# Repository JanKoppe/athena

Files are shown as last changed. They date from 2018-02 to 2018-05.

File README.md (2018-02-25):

# Athena

_2.1 audio crossover and headphone amplifier_

This is a work-in-progress on a simple 2.1 audio crossover using active 2nd-order RC filters, as well as a headphone amplifier based on the popular CMoy design. The PCBs have not yet been ordered and confirmed.

## Crossover frequency

The crossover frequency is set by the resistors R11-R16 and the capacitors C5-C10. Keep the values for all components the same.

equation

Using a fixed, commonly available 100nF capacitor the following (and more) corner frequencies can be set:

Resistance | Frequency
-----------|----------
22 kOhms   |  72,34 Hz
20 kOhms   |  79,57 Hz
18 kOhms   |  88,42 Hz
16 kOhms   |  99,47 Hz
15 kOhms   | 106,10 Hz
13 kOhms   | 122,48 Hz
12 kOhms   | 132,64 Hz

## Power supply

The unit should be powered by at least 12 volts DC, but no more than 30 volts DC. More voltage will give you higher headroom for greater amplification (headphone) and high-level signal handling, though you should be able to use a regular 12 volts DC power supply for consumer line levels.

__Attention:__ The power supply must _never_ be connected to signal ground because this schematic referencing ground to VCC/2, i.e. the power supply ground is actually the negative voltage rail. Using a wall wart power supply you should not run into any issues. This avoids adding large capacitors in series on the outputs.

## Enclosure

Use Fischer Elektronik KOH-1100 and KOH-2100 case components with lasercut panels from 2mm plexiglas for the enclosure. CAD files for panel cutouts are included.

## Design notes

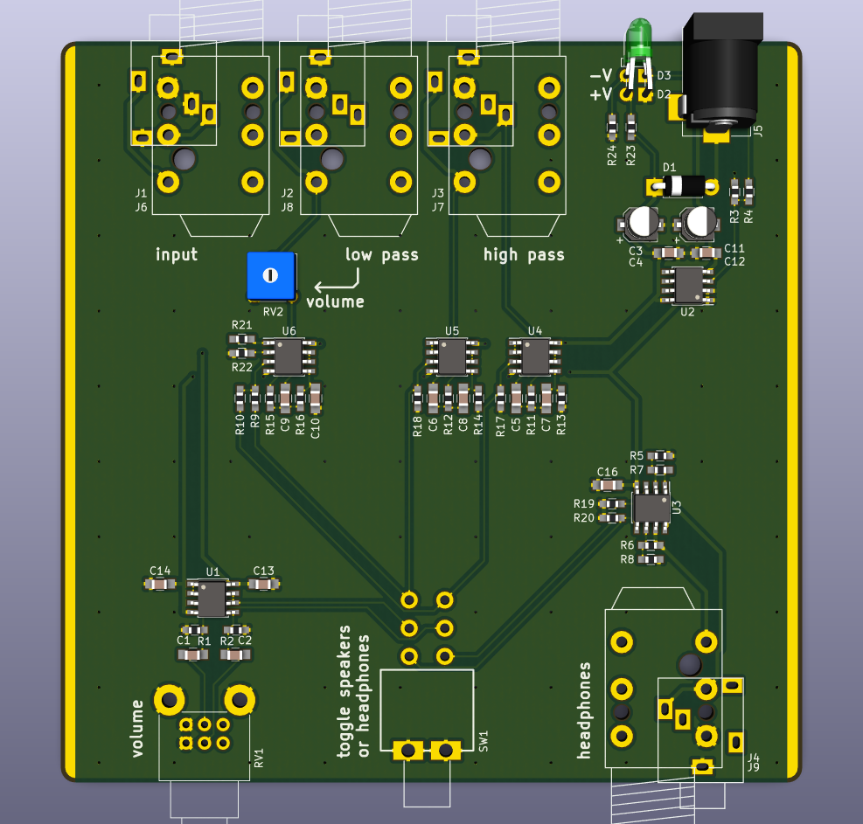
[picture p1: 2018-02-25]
3d_top.png

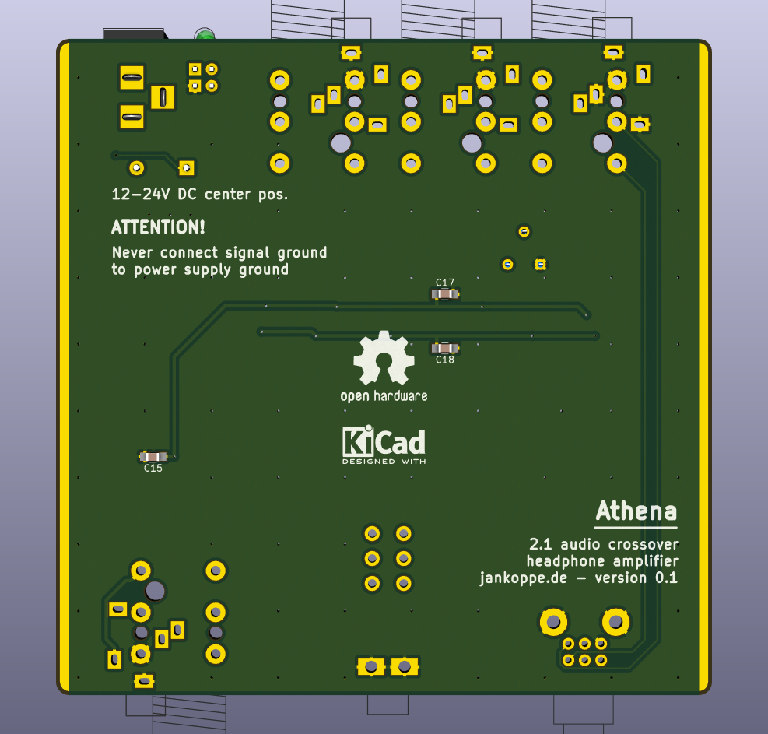
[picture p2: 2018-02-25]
3d_bottom.png

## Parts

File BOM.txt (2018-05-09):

4x NE5532 SOIC-8 (U1, U4-6) (input buffer and active filters for speaker outputs)
1x OPA2134 SOIC-8 (U3) (opamp for cmoy, needs beefy output)
1x TL072 SOIC-8 (U2) (voltage rail splitter buffer)
2x 10u/16v smd electrolytic capacitor (C3, C11)
16x 100n 0805 ceramic capacitor (all other C)
6x 10k 0603 resistor (R3, R4, R9, R10, R21, R22)
6x 100k 0603 resistor (R1, R2, R17-20)
6x 22k 0603 resistor (R11-16)
2x 2k7 0603 resistor (R5, R6)
2x 8k2 0603 resistor (R7, R8)
2x 330r resistor (R23, R24) (current-limiting resistors for voltage leds)
2x 3mm LED of your choice (D2, D3) (voltage indicator leds)
1x 1n4001 diode (D1)
1x 10k single turn trimmer, flat, legs (RV2) - sub volume
1x alps RK09L12B 10k log stereo potentiometer (RV1) - main volume
1x "MS 500FVT"@reichelt.de switch, DPDT (SW1)
1x standard DC 2.1mm pcb-mount jack

Input/Output Jacks can be selected to your liking between 3.5mm and 6.3mm jacks, you will need a total of 4 jacks:
Neutrik NRJ6HF for 6.3mm and corresponding nut
Lumberg 1503-09 for 3.5mm

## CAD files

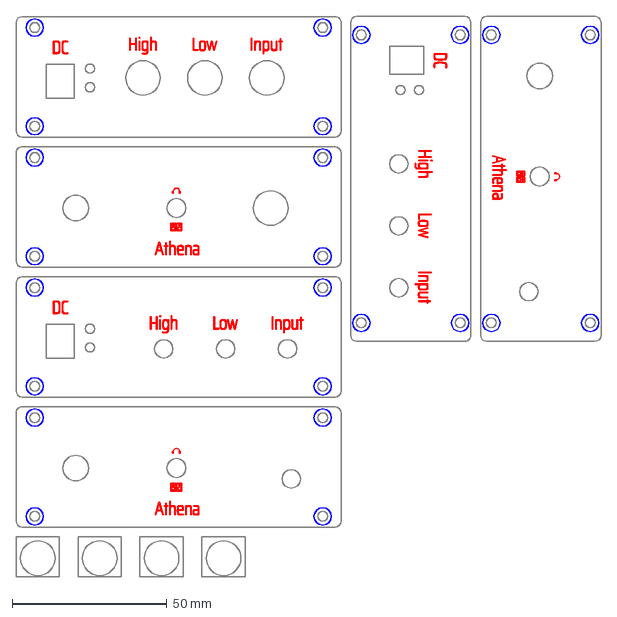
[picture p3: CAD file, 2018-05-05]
panels/panels.dxf
188.9 x 181.0 mm

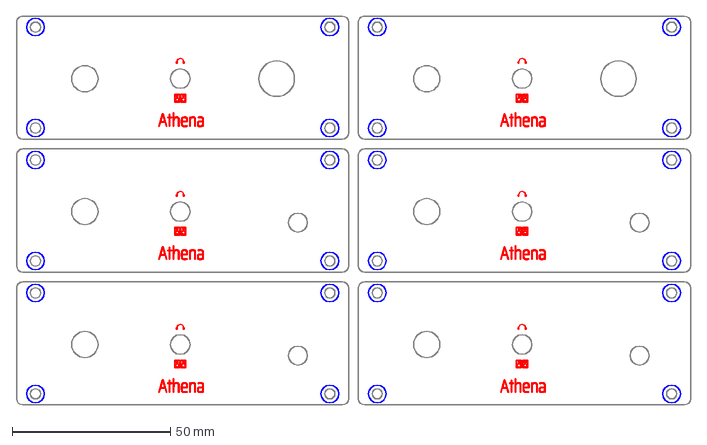
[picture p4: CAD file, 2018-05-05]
panels/panels_fixed_front.dxf
213.0 x 122.9 mm

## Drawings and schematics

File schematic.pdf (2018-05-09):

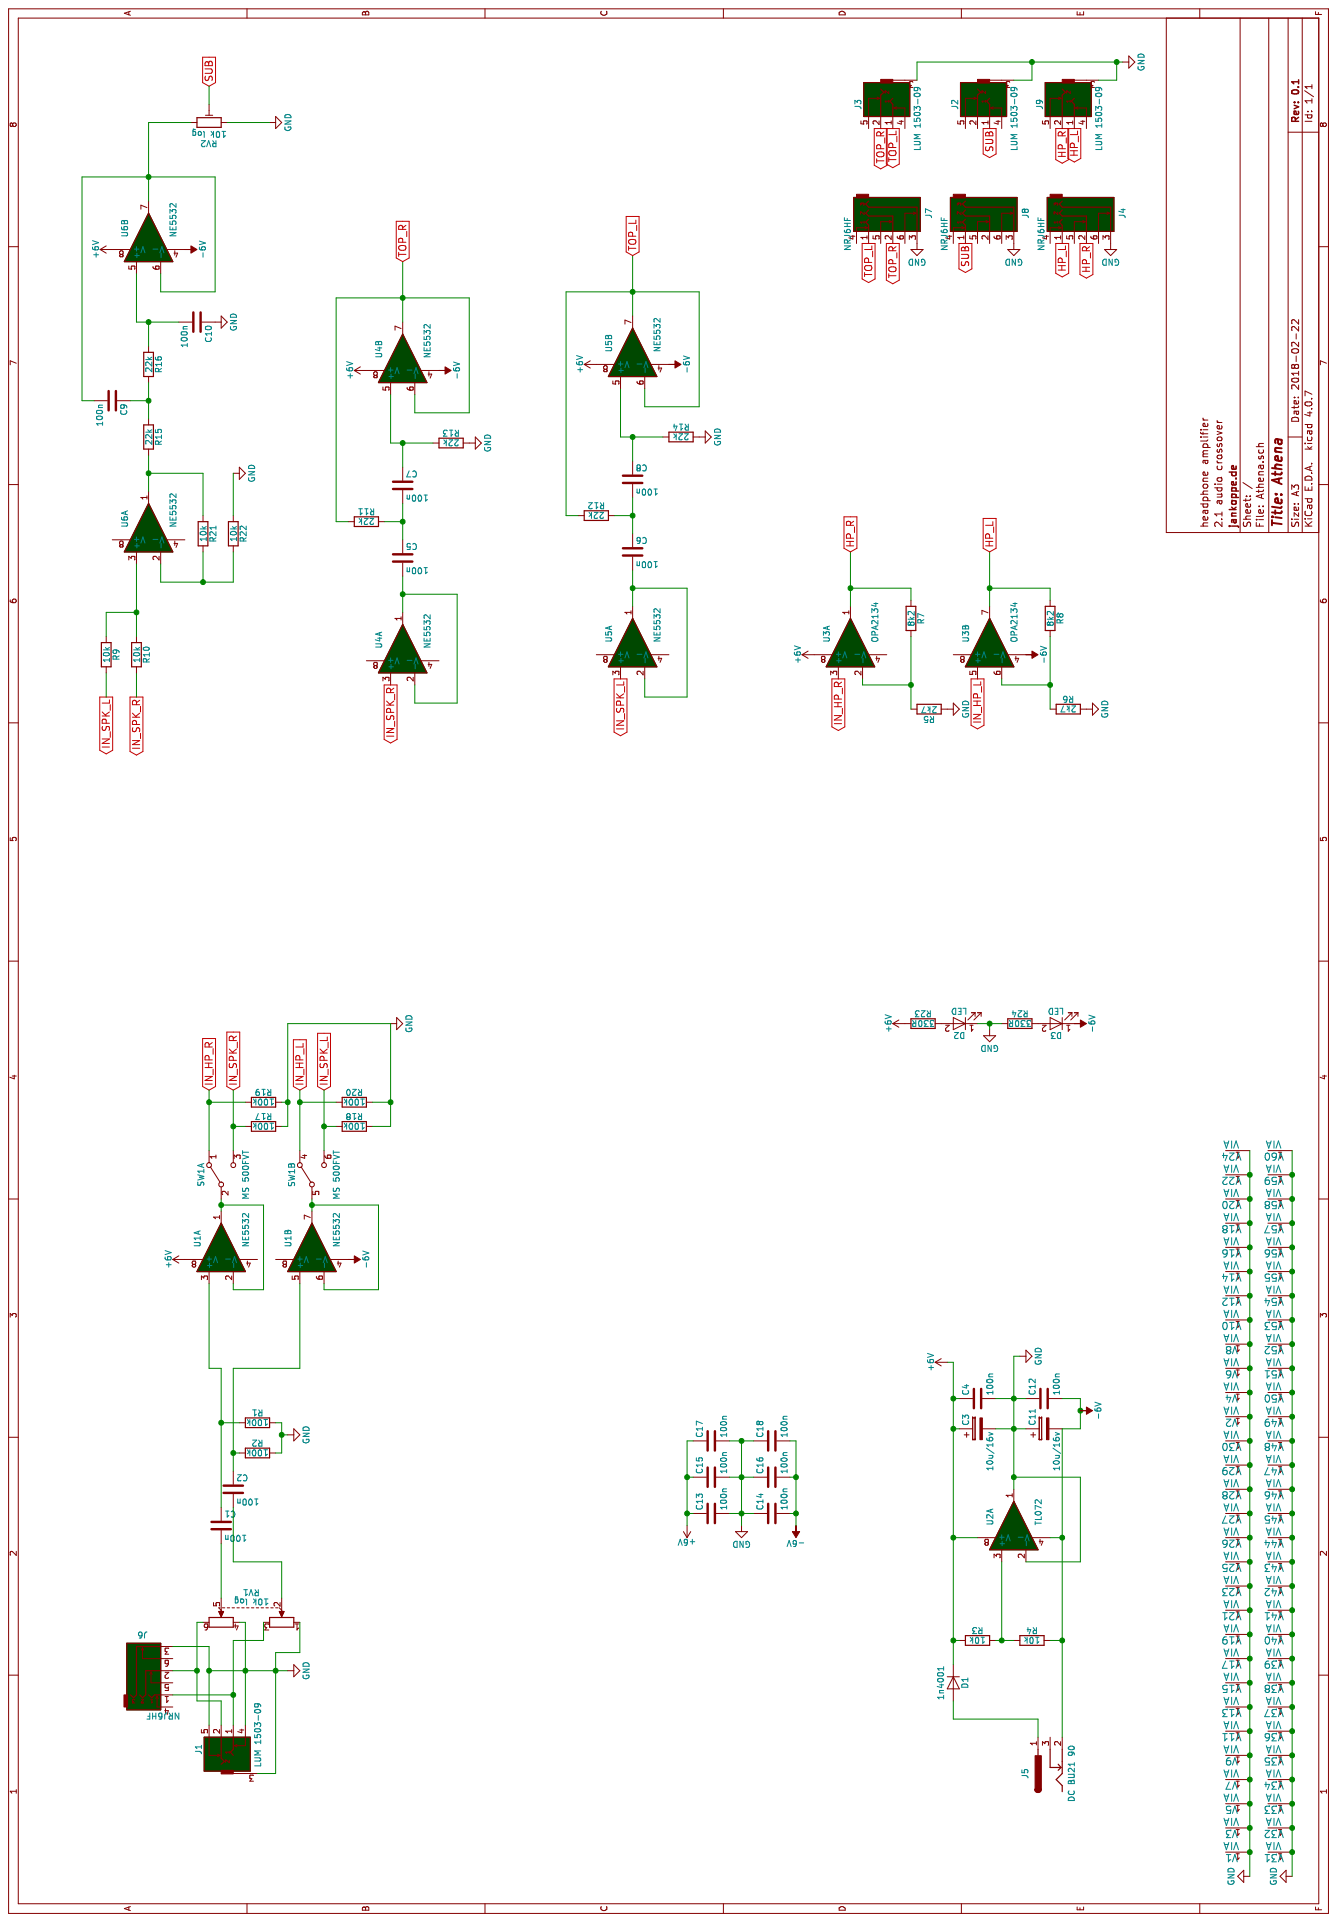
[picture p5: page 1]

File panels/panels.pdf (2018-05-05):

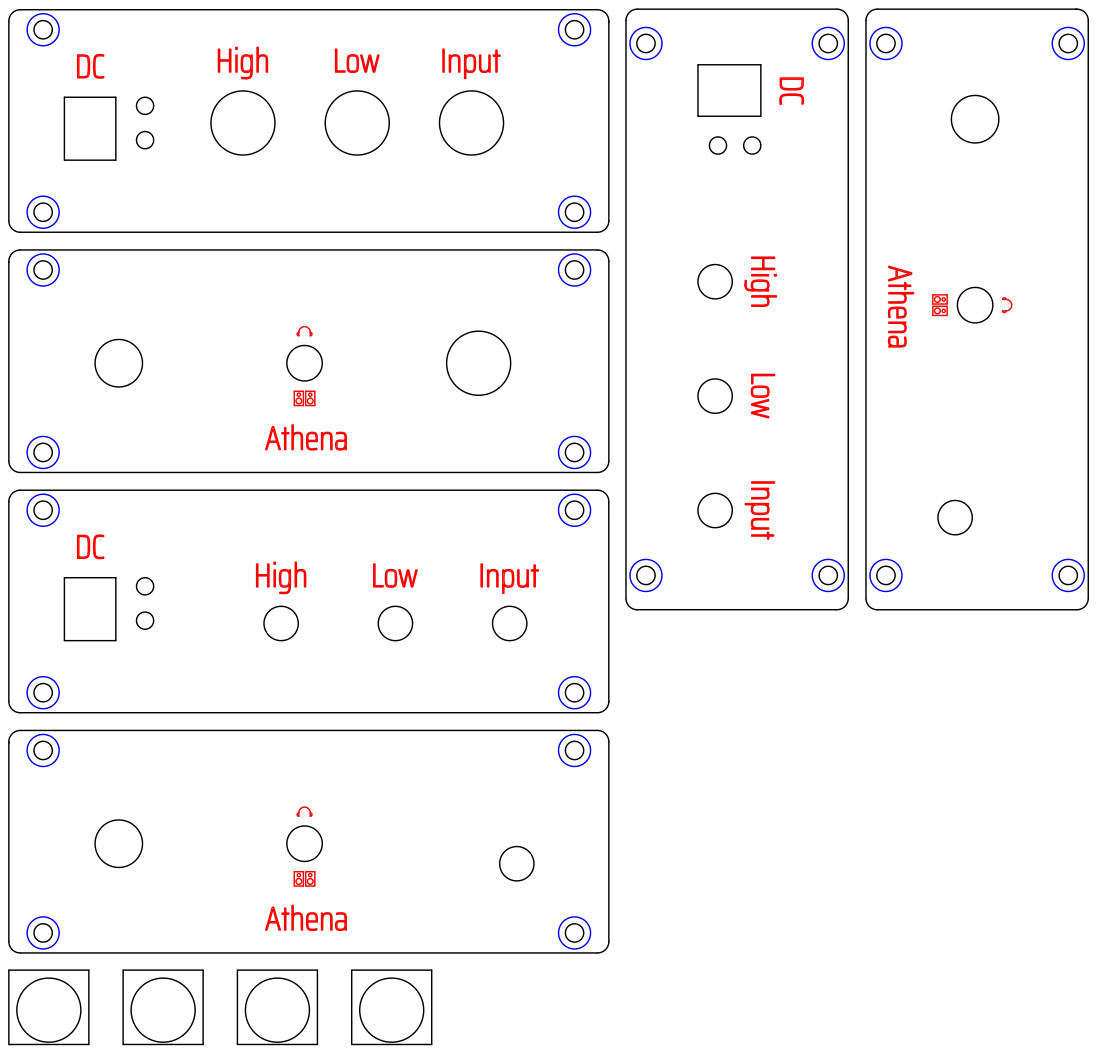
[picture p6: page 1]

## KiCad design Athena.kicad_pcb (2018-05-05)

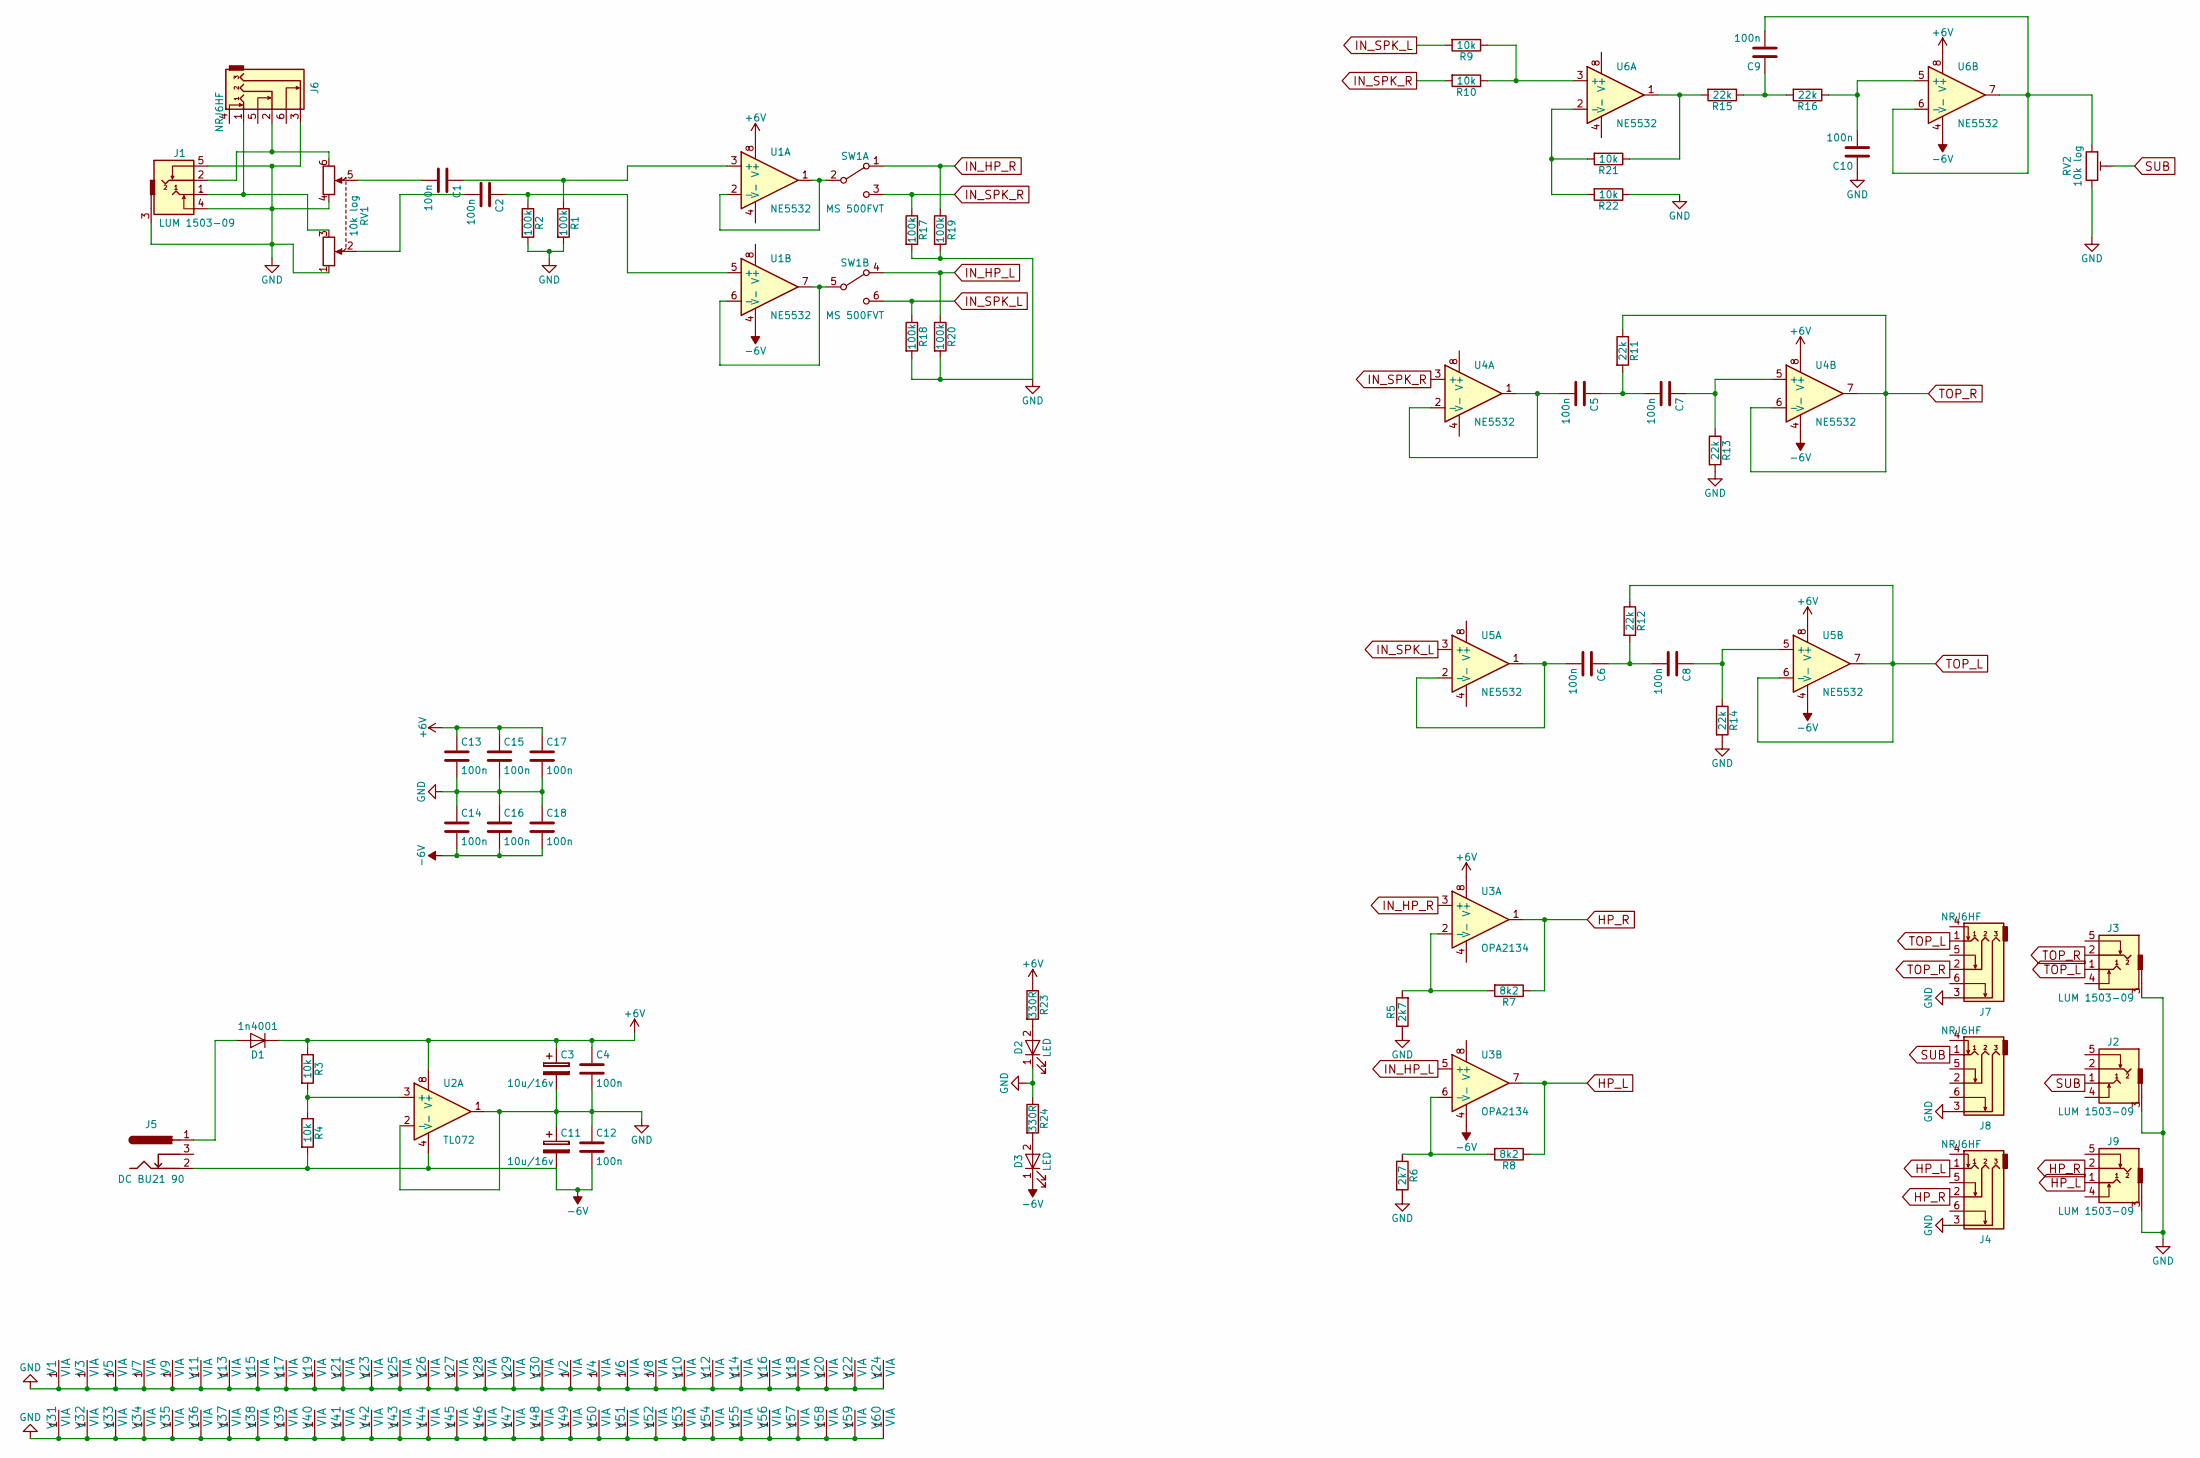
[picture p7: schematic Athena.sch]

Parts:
C1, C2, C4, C5, C6, C7, C8, C9, C10, C12, C13, C14, C15, C16, C17, C18: 100n; C_0805_HandSoldering
C3, C11: 10u/16v; CP_Elec_4x5.3
D1: 1n4001; D_DO-41_SOD81_P7.62mm_Horizontal
D2: LED; LED_D3.0mm_Horizontal_O3.81mm_Z6.0mm
D3: LED; LED_D3.0mm_Horizontal_O1.27mm_Z2.0mm
J1, J2, J3, J9: LUM 1503-09; LUM1503-09
J4, J6, J7, J8: NRJ6HF
J5: DC BU21 90; BARREL_JACK
R1, R2, R17, R18, R19, R20: 100k; R_0603_HandSoldering
R3, R4, R9, R10, R21, R22: 10k; R_0603_HandSoldering
R5, R6: 2k7; R_0603_HandSoldering
R7, R8: 8k2; R_0603_HandSoldering
R11, R12, R13, R14, R15, R16: 22k; R_0603_HandSoldering
R23, R24: 330R; R_0603_HandSoldering
RV1: 10k log; Potentiometer_Alps_RK09L_Double_Vertical
RV2: 10k log; Potentiometer_Trimmer_ACP_CA6v_Horizontal
SW1: MS 500FVT; MS500FVT
U1, U4, U5, U6: NE5532; SOIC-8_3.9x4.9mm_Pitch1.27mm
U2: TL072; SOIC-8_3.9x4.9mm_Pitch1.27mm
U3: OPA2134; SOIC-8_3.9x4.9mm_Pitch1.27mm
V1, V2, V3, V4, V5, V6, V7, V8, V9, V10, V11, V12, V13, V14, V15, V16, V17, V18, V19, V20, V21, V22, V23, V24, V25, V26, V27, V28, V29, V30, V31, V32, V33, V34, V35, V36, V37, V38, V39, V40, V41, V42, V43, V44, V45, V46, V47, V48, V49, V50, V51, V52, V53, V54, V55, V56, V57, V58, V59, V60: VIA; VIA-0.6

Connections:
+6V: C3.1, C4.1, C13.1, C15.1, C17.1, D1.1 (K), R3.1, R23.1, U1.8 (V+), U2.8 (V+), U3.8 (V+), U4.8 (V+), U5.8 (V+), U6.8 (V+)
-6V: C11.2, C12.2, C14.2, C16.2, C18.2, D3.1 (K), J5.2, R4.2, U1.4 (V-), U2.4 (V-), U3.4 (V-), U4.4 (V-), U5.4 (V-), U6.4 (V-)
GND: C3.2, C4.2, C10.1, C11.1, C12.1, C13.2, C14.1, C15.2, C16.1, C17.2, C18.1, D2.1 (K), J1.3, J1.4, J1.5, J2.3, J3.3, J4.3, J6.3, J7.3, J8.3, J9.3, R1.2, R2.2, R5.1, R6.2, R13.2, R14.2, R17.2, R18.2, R19.2, R20.2, R22.1, R24.1, RV1.0, RV1.1, RV1.4, RV2.3, U2.1, U2.2 (-), V1.1, V2.1, V3.1, V4.1, V5.1, V6.1, V7.1, V8.1, V9.1, V10.1, V11.1, V12.1, V13.1, V14.1, V15.1, V16.1, V17.1, V18.1, V19.1, V20.1, V21.1, V22.1, V23.1, V24.1, V25.1, V26.1, V27.1, V28.1, V29.1, V30.1, V31.1, V32.1, V33.1, V34.1, V35.1, V36.1, V37.1, V38.1, V39.1, V40.1, V41.1, V42.1, V43.1, V44.1, V45.1, V46.1, V47.1, V48.1, V49.1, V50.1, V51.1, V52.1, V53.1, V54.1, V55.1, V56.1, V57.1, V58.1, V59.1, V60.1; also elsewhere on the board
HP_L: J4.1, J9.1, R8.1, U3.7
HP_R: J4.2, J9.2, R7.1, U3.1
IN_HP_L: R20.1, SW1.4 (A), U3.5 (+)
IN_HP_R: R19.1, SW1.1 (A), U3.3 (+)
IN_SPK_L: R9.2, R18.1, SW1.6 (C), U5.3 (+)
IN_SPK_R: R10.2, R17.1, SW1.3 (C), U4.3 (+)
unnamed: C1.1, R1.1, U1.3 (+)
unnamed: C1.2, RV1.5
unnamed: C2.1, R2.1, U1.5 (+)
unnamed: C2.2, RV1.2
unnamed: C5.1, C7.2, R11.2
unnamed: C5.2, U4.1, U4.2 (-)
unnamed: C6.1, C8.2, R12.2
unnamed: C6.2, U5.1, U5.2 (-)
unnamed: C7.1, R13.1, U4.5 (+)
unnamed: C8.1, R14.1, U5.5 (+)
unnamed: C9.1, R15.1, R16.2
unnamed: C9.2, RV2.1, U6.6 (-), U6.7
unnamed: C10.2, R16.1, U6.5 (+)
unnamed: D1.2 (A), J5.1
unnamed: D2.2 (A), R23.2
unnamed: D3.2 (A), R24.2
unnamed: J1.1, J6.1, RV1.3
unnamed: J1.2, J6.2, RV1.6
unnamed: R3.2, R4.1, U2.3 (+)
unnamed: R5.2, R7.2, U3.2 (-)
unnamed: R6.1, R8.2, U3.6 (-)
unnamed: R9.1, R10.1, U6.3 (+)
unnamed: R15.2, R21.1, U6.1
unnamed: R21.2, R22.2, U6.2 (-)
unnamed: SW1.2 (B), U1.1, U1.2 (-)
unnamed: SW1.5 (B), U1.6 (-), U1.7
SUB: J2.1, J8.1, RV2.2
TOP_L: J3.1, J7.1, R12.1, U5.6 (-), U5.7
TOP_R: J3.2, J7.2, R11.1, U4.6 (-), U4.7

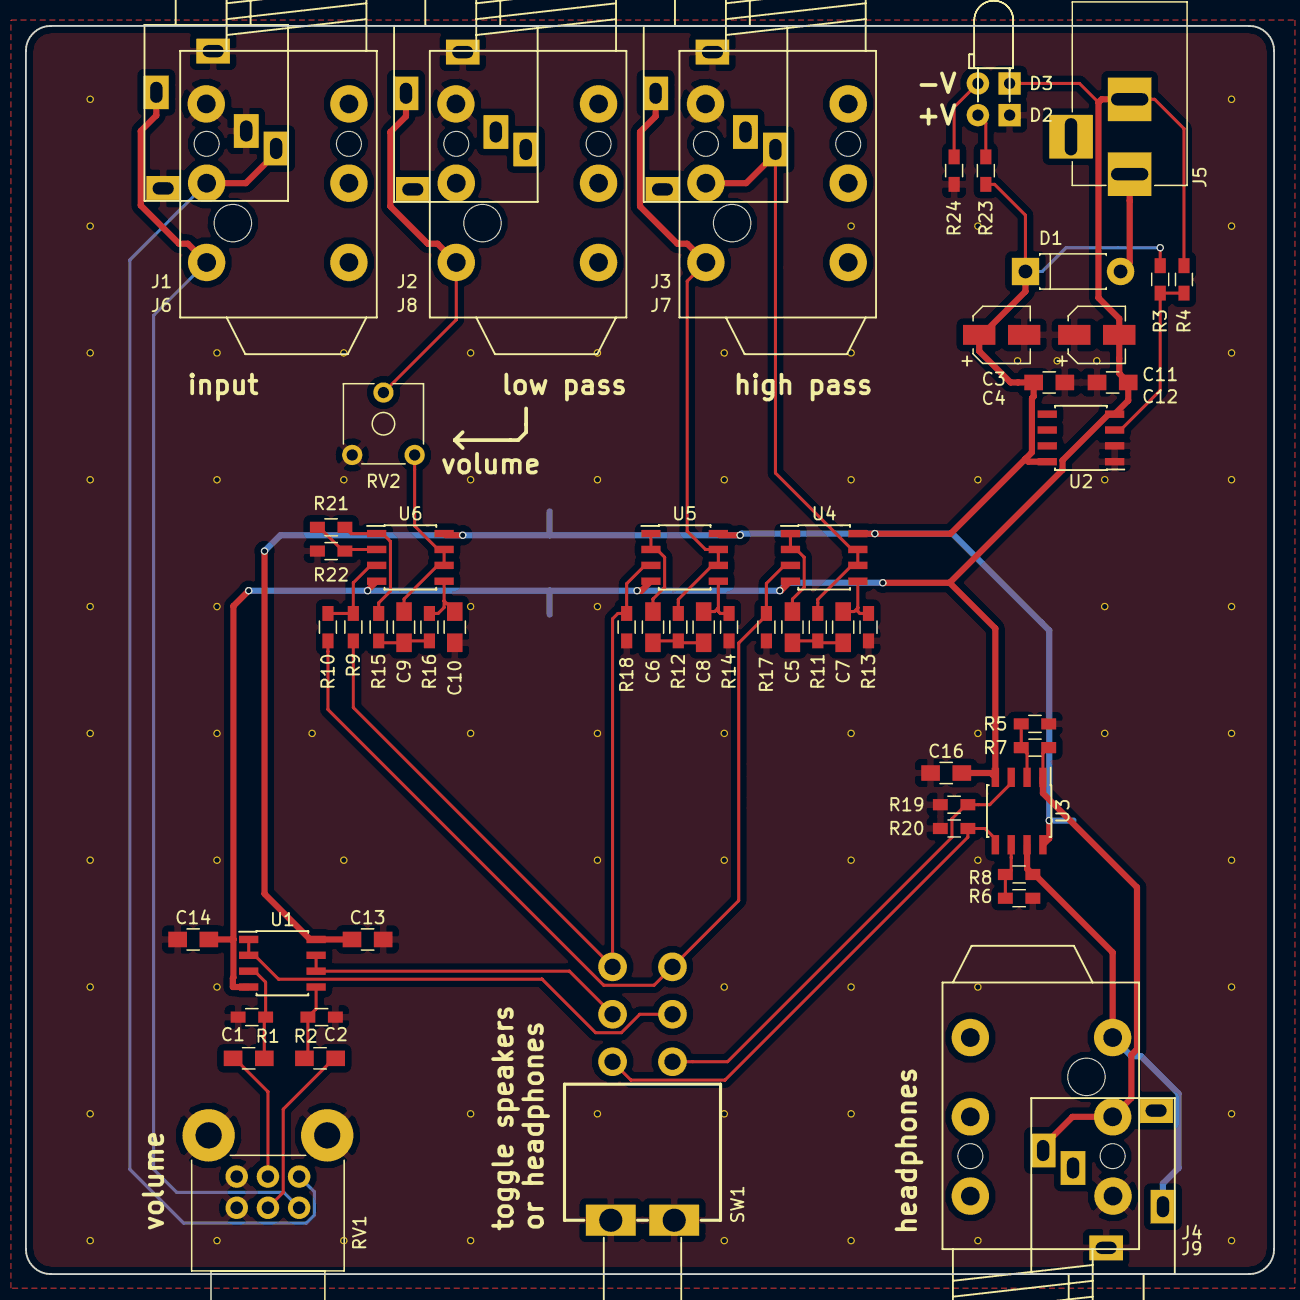
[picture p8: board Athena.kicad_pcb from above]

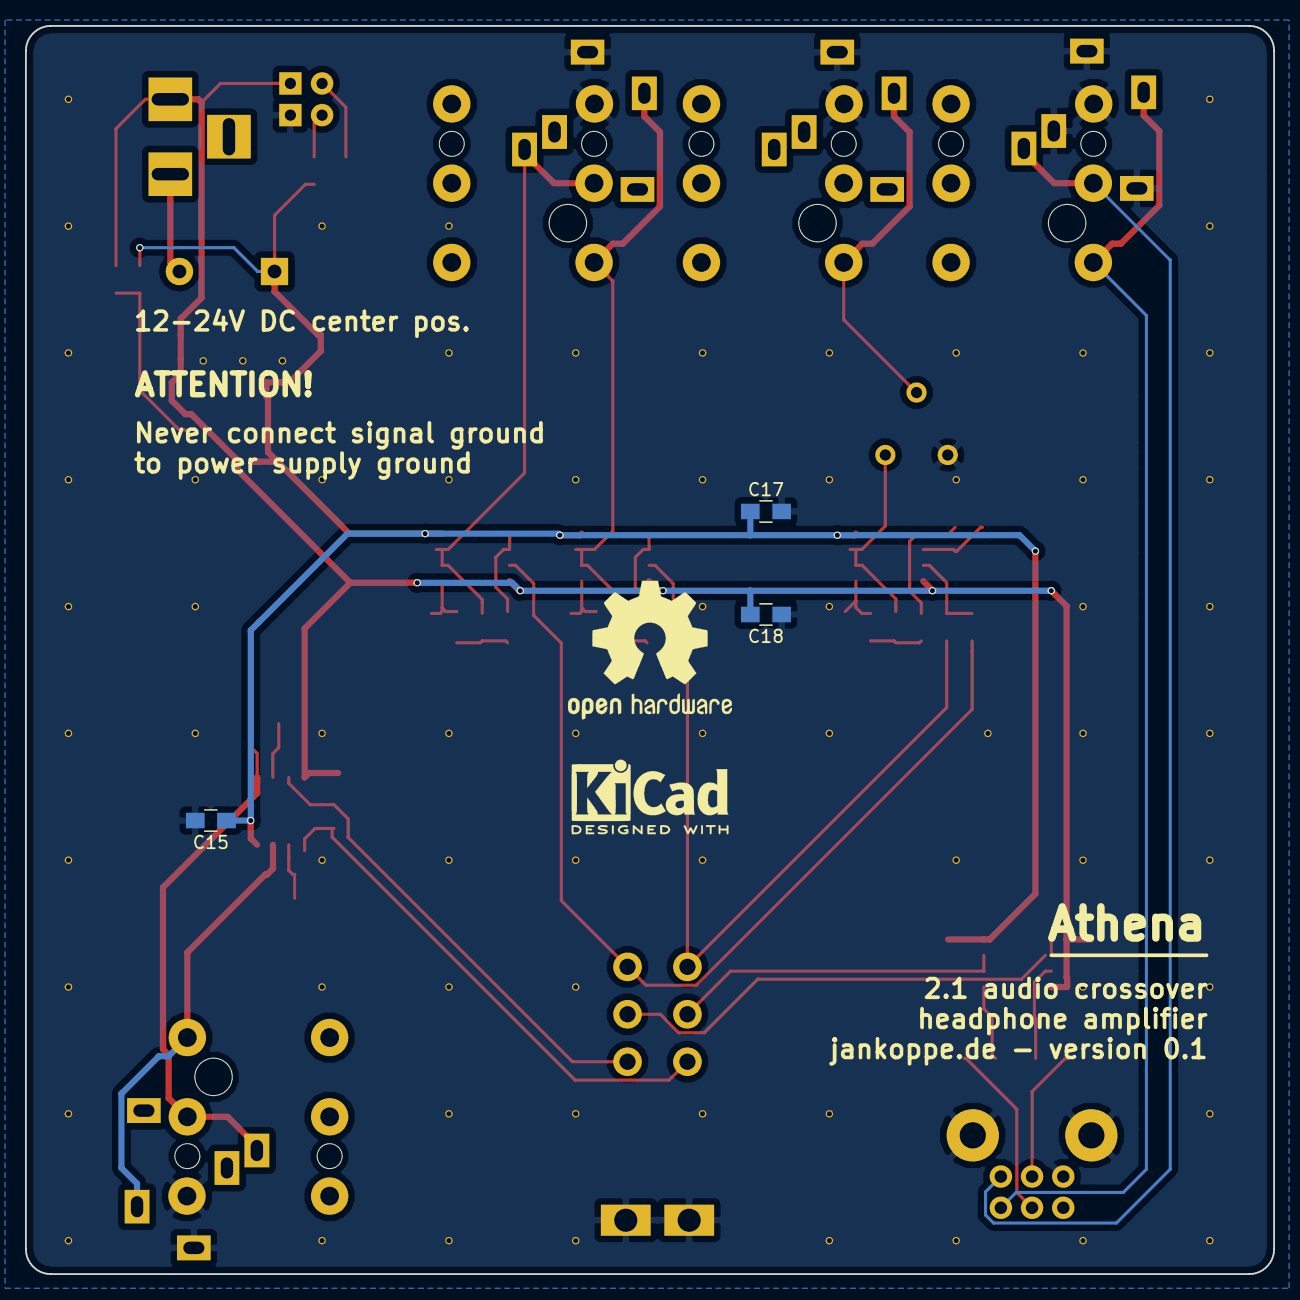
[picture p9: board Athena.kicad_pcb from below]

Board: 2 copper layers, 100.0 x 100.0 mm, 134 parts (3 on the bottom side), 38 nets.

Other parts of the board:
V30#2, V30#3, V30#4, V30#5, V30#6, V30#7, V30#8, V30#9, V30#10, V30#11, V30#12: VIA; VIA-0.6

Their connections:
GND: V30#2.1, V30#3.1, V30#4.1, V30#5.1, V30#6.1, V30#7.1, V30#8.1, V30#9.1, V30#10.1, V30#11.1, V30#12.1; also elsewhere on the board

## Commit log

2018-02-22 version 0.1
    [Athena.kicad_pcb, Athena.sch]
2018-02-25 changed enclosure, added power leds, resized pcb
    [Athena-B.Cu.gbr, Athena-B.Mask.gbr, Athena-B.Paste.gbr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]
2018-05-05 weee i need to clean up
    [Athena.kicad_pcb, panels.dxf, panels_fixed_front.dxf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]
2018-05-09 update schematic and BOM
